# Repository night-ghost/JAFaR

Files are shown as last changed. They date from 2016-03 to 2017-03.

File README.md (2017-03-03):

The original pkendall64 version not works or even not compiles for me so this is easy-build version with almost the same functions

## pkendall64's original README follows

# JAFaR (Just Another Fatshark Receiver Module)

DIY OpenSource 40ch receiver OSD integrated

## This is a major refactor of MikyM0use's original code

**Changes**
* Added a favorites section which remembers the last 8 channels used ordered with the last used at the top of the list. It re-orders the list when you select a new channel.
* The scanner is continuously running in the main menu or scanner menu. This means that the RSSI values are pretty much always up to date.
* There's a timer progress bar on the right rather than a counter.
* Double-click (i.e. another press within 1 second) takes you back to the main menu.
* When in a band selection menu, favorites or autoscan a single click of the buttons selects the next or previous channel respectively.
* When a channel is selected, display the current RSSI for each receiver under the channel designator (only on the OLED display).
* Moved all strings in OLED and OSD to PROGMEM.

Make sure to use the updated TVout library from https://github.com/pkendall64/arduino-tvout as the original will cancel timer 2, which is the selection timer for this version of the receiver.

## MikyM0use's original README follows

The aim of the project is to build an opensource 40ch receiver for Fatshark goggles which has to be easy to develop,
upgrade and maintain. And, of course, it must be cheap!
<p align="center">
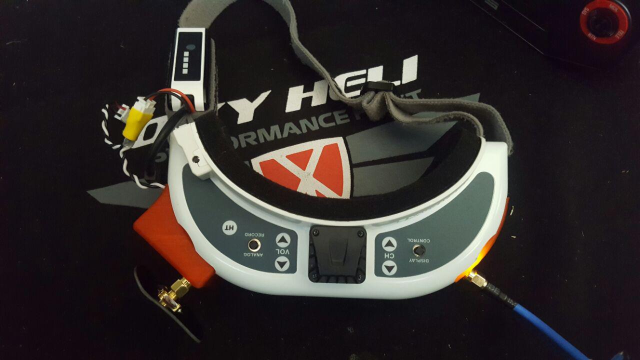
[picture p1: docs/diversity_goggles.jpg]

</p>

* 40ch (8 channels for 5 bands, including race band)
* No external switch, or hall effect sensor, or buzzer, it must use __only__ the goggles buttons (up-down)
* Auto search feature
* It should include the “scanner” feature (see my recent project here https://github.com/MikyM0use/OLED-scanner)
* Frequency selection via OSD inside the goggles
* I tested it only with Fatshark HD but the module should work with every Fatshark with the RX external module (like Dominator V1, V2, V3, HD, HD2...)

This project uses the “RX5808” receiver module, which can be hacked to be SPI-programmed by a microcontroller (more details later).
So what I needed is a micro controller with an easy and well-know software IDE… nothing better than Arduino. So I decided to use an Atmega 328p as micro controller.

To select the frequency there's a series of menus on the screen inside the goggles, the
useful TVOUT Arduino library is perfect and requires just a couple of resistors
(http://playground.arduino.cc/Main/TVout).
A digital switch (TS5A3359) allow to switch from OSD to the normal receiving video from the quadcopter.

The project is mainly divided into two PCBs:
* one main base module
* one "diversity" daughterboard (optional)

it's also possibile to use an SPI-OLED display and use the module as standalone RX.

##Table of contents
* [Main module](#main-module)
	* [DIY Instructions](#diy-instructions)
	* [MAIN MODULE Troubleshooting](#main-module-troubleshooting)
* [Diversity module](#diversity-module)
* [OLED module](#oled-module)
* [STANDALONE mode](#standalone-mode)
* [Reference thread](#reference-thread)
* [FAQ:](#faq)
* [Donations:](#donations)

##Main module

This is the main RX module, usable alone as a 40ch receiver module, but if you connect an
"external" module, the onboard microcontroller can decide which RX module has better
reception (so-called "diversity") based on the received signal strength. Indeed, this
RX5808 modules has an analog output called RSSI proportional on the "quality" of the
received video signal. The receiving video channel (frequency) is set by the user using an OSD menu.

<p align="center">
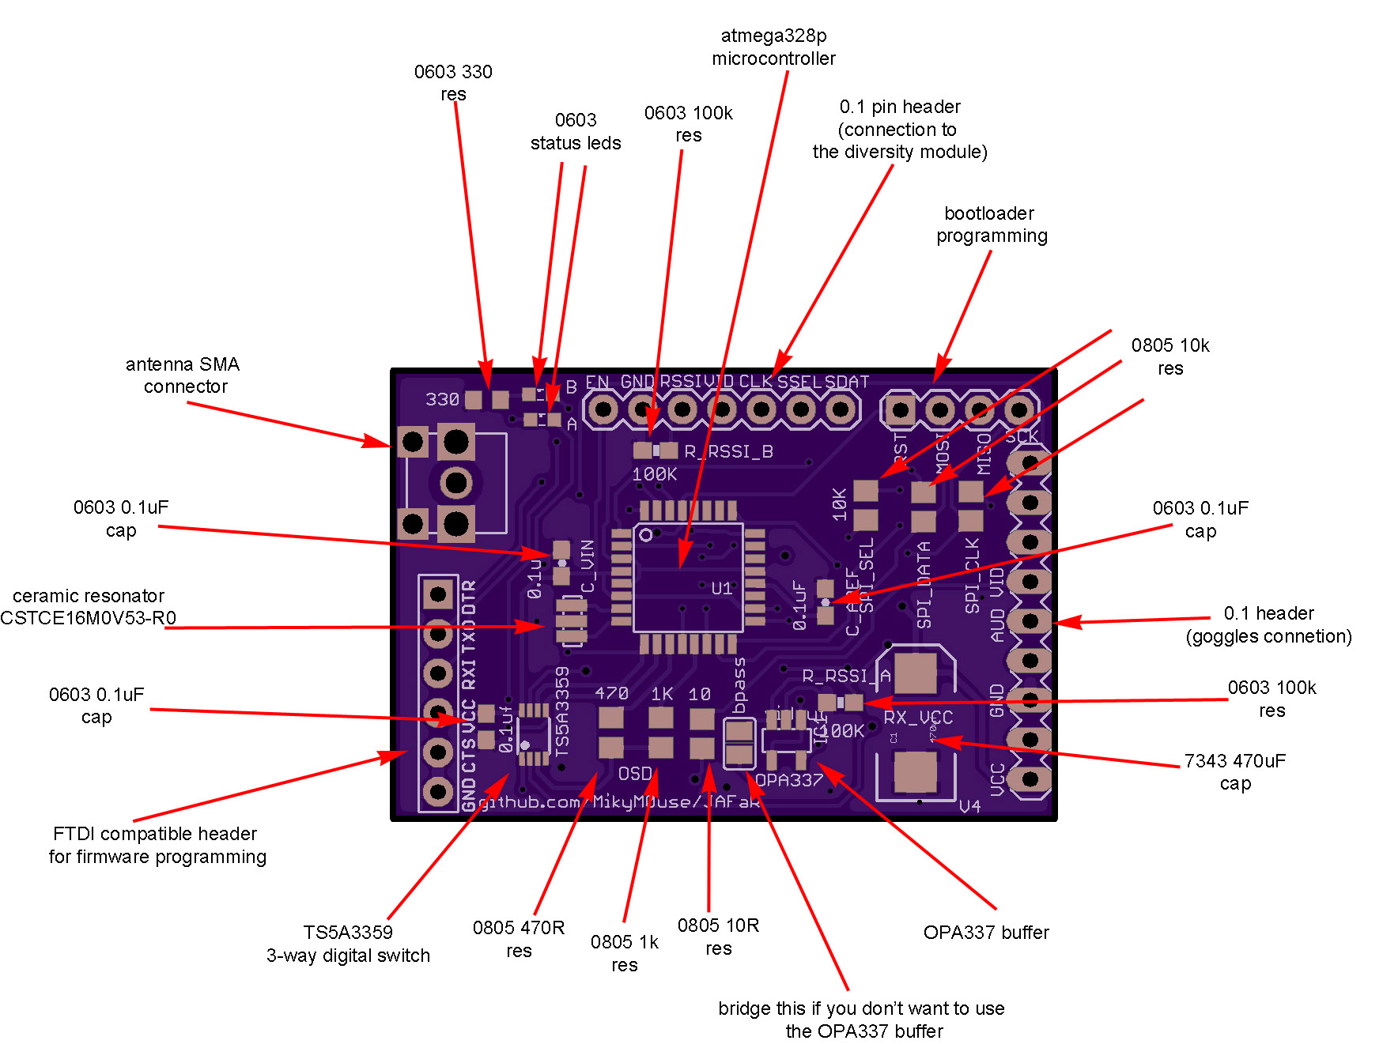
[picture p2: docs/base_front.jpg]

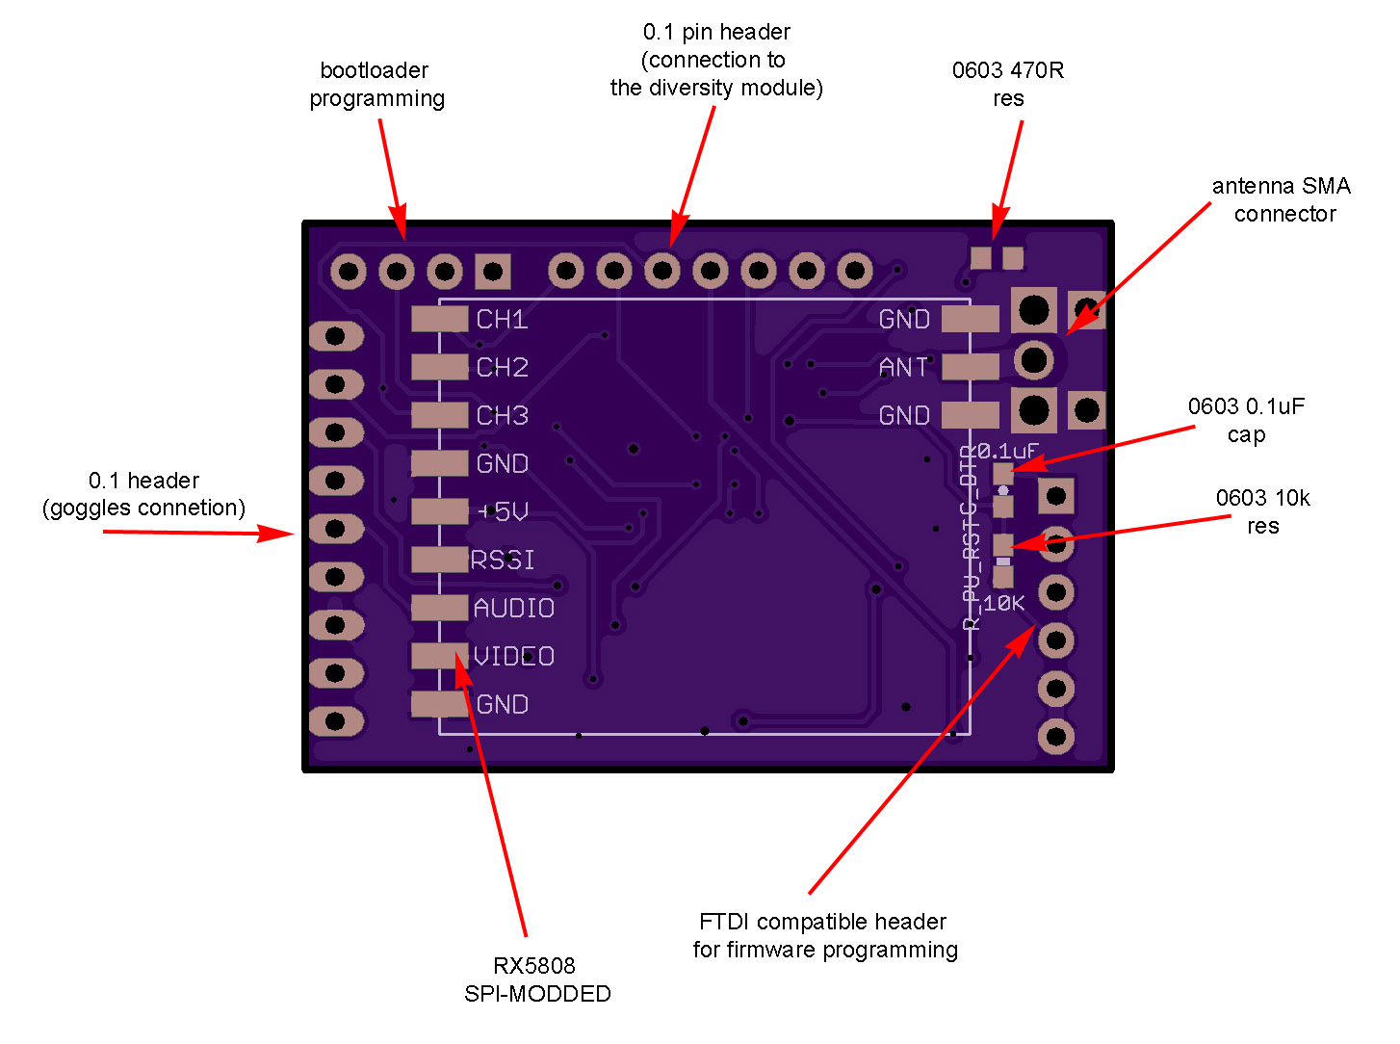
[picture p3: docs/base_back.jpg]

</p>

__MAIN MODULE (V4.0) BOM__

https://docs.google.com/spreadsheets/d/1CrZzOQHyK_d1VfHCQKwdNuoyMji0IYryI1VuffojdGA/edit?usp=sharing

__LEGACY MAIN MODULE (V3.2)__

This module is actually the same as the v4.0, but it doesn't have the buffer on the RSSI output,
and the PCB allows the use of a capacitor OR a resistor on the video out. DON'T use both! after some
tests I realized that a 10ohm resistor (and no cap) is enough.

<p align="center">
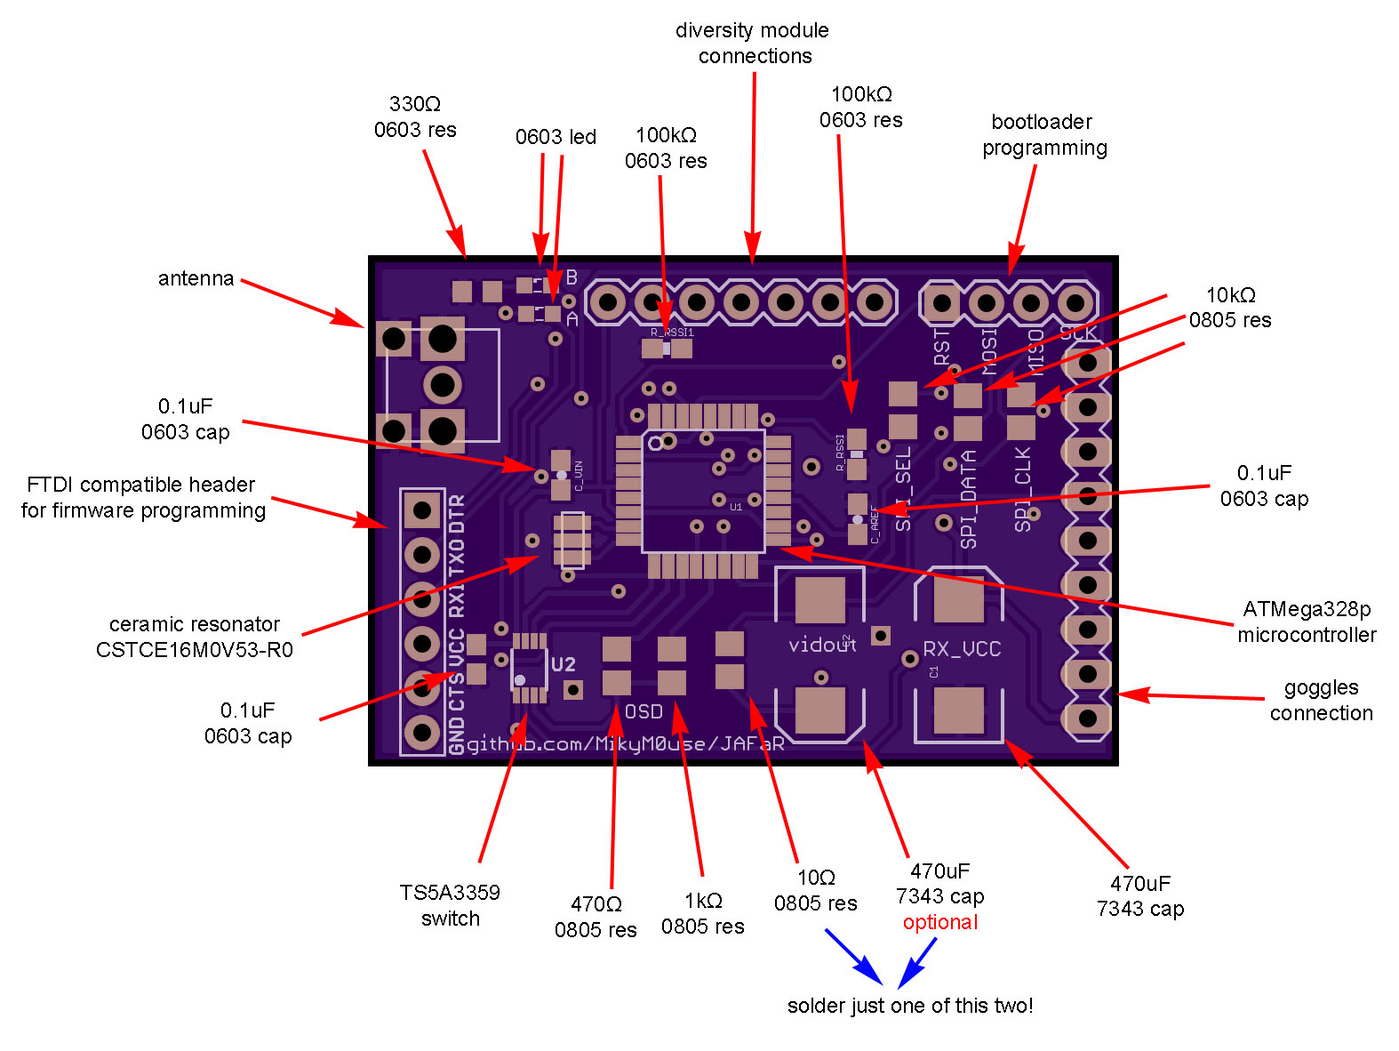
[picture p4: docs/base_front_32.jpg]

</p>

(the back side is the same of the v4.0).

__LEGACY MAIN MODULE (V3.2) BOM__

https://docs.google.com/spreadsheets/d/1-763imBV3QsQ71GKDZH-BirTz1k32szNuJZUKQrE00g/edit?usp=sharing

###DIY Instructions

1. Remove the shield of the RX5808 module and desolder the resistor marked by the arrow. This
is the SPI-mod required to control the module with an external microcontroller.

<p align="center">
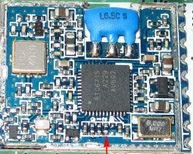
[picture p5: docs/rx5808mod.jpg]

</p>

2. Follow the instructions on the page https://www.arduino.cc/en/Tutorial/ArduinoISP to burn the bootloader (select __"Arduino Pro Mini 5v 16MHz"__ as target board)
using the pins in the upper right corner of the board

3. Use the FTDI connections in the left side of the board to upload the code present in the
Github page of the project. Please remember to copy all the subfolders of "libs" dir in the
libraries folder of Arduino (e.g. /Arduino/libraries).
Here you can find more infos and alternative methods to import the libraries:
https://www.arduino.cc/en/Guide/Libraries

4. When you power on the module, BOTH the leds (upper left corner of the pcb) must be on, and you must see a relatively stable splash screen for about 5 seconds

5. The very first time you power on the module, it need to calibrate itself. So please turn on the module with a working Vtx a couple of meter away (the video frequency doesn't matter). This process can take a while (about 30-50 seconds).

6. You can now use the "selection" buttons on the goggles to scroll up/down the menu to select the band

7. After the timout of the countdown (upper left corner of the screen) you entered the frequency selection (of the selected band)

8. Scroll up/down to select the frequency and wait the timeout

9. At this moment only one led on the module has to be ON, it means that the RX video output is routed to the video_input of the goggles. If you have a Vtx near, you should see the video coming from it.

10. If you press the "selection" buttons of the goggles now, you change the frequency by the 8 frequencies of the previously selected band.

###MAIN MODULE Troubleshooting

After the initial calibration, the module must turn on in couple of seconds and you must see the splash screen for some seconds before the "band selection" screen.
In the "band selection" screen you can see the 5 bands with the percentage of the maximum RSSI detected on that band. At least one of the band must be at 98-100%.
If you "enter" one band, every channel must shows a different percentage of RSSI, otherwise the SPI-mod of the module could be failed.

__Unable to flash/Aduino issues:__

(thanks to pHysiX for the help in this section!)
Got the error "no reply" when trying to load the firmware:
the ATmega microcontroller is not soldered properly / there is a short on some pins.
try a quick solder, clean and reflow.

Got the error "incorrect signature" when trying to load the firmware:
This means Arduino is able to pick up the ATMega, but it was not communicating as expected.
This is related to poor soldering of the crystal. It's possible to do the crystal using
an iron, but I strongly recommend using flow method/hot air to do this, to make sure you
don't short the three legs accidentally onto the metal case.

__Display issues:__

They are mostly related to poor soldering for the OSD components on the board. Go back and
reflow especially the Switch, and then just make sure to clean up and touch up all the caps
and resistors near and around the switch.

If you have an external monitor, you can bypass the digital switch by power on the module with external 5v and connecting the "video in" of the monitor on the test point marked in yellow the picture:

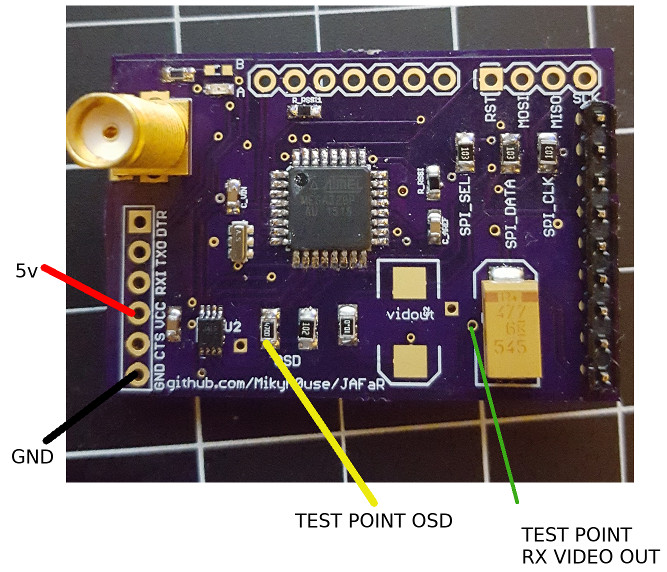
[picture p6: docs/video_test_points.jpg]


and you should see the splash screen and the menu.

If you connect the "video in" of the monitor to the test point marked in green, you should see the initial scanning (used to determine the % of the RSSI on each channel), this means a sequence of different "fogs" and (at least) one "good" image (for a fraction of second), if you have a Vtx + cam transmitting.

__Frequency issues:__

If the module is having trouble Setting Frequency, or you are not getting video when you are
on the right channel and frequency, make sure the SPI mod has been done, and that the RX5808
is soldered on well. Pretty hard to mess this part up.

##Diversity module

The diversity module is an optional second receiver, connected to the "main" base module, it has:
* integrated linear 5v regulator with ENABLE feature connected to the VCC of the main module.
In fact power a second module from the internal goggles voltage regulator IS VERY DANGEROUS!
* an optional operational buffer for RSSI signal (I noticed that lately modules seems to be more delicate)

<p align="center">
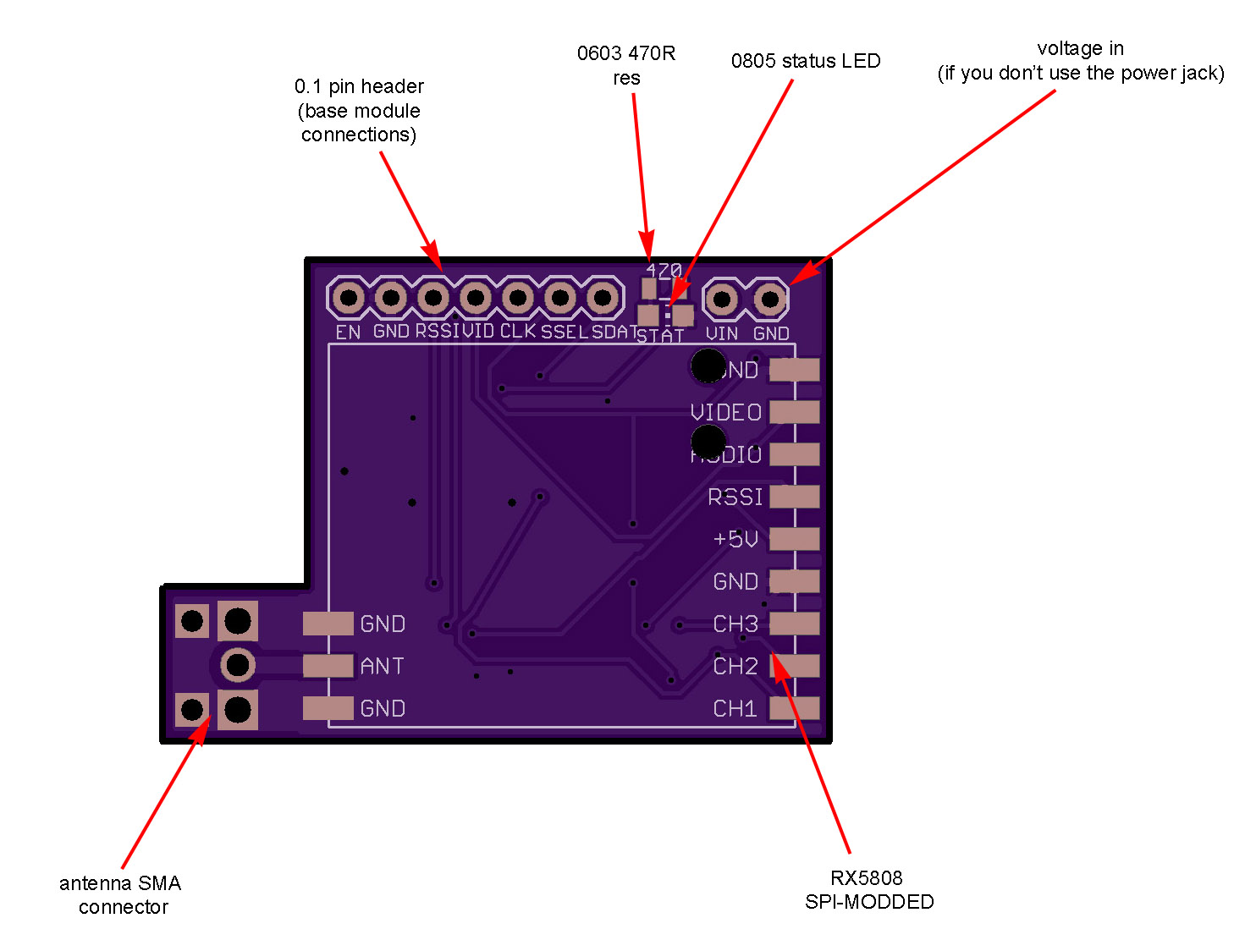
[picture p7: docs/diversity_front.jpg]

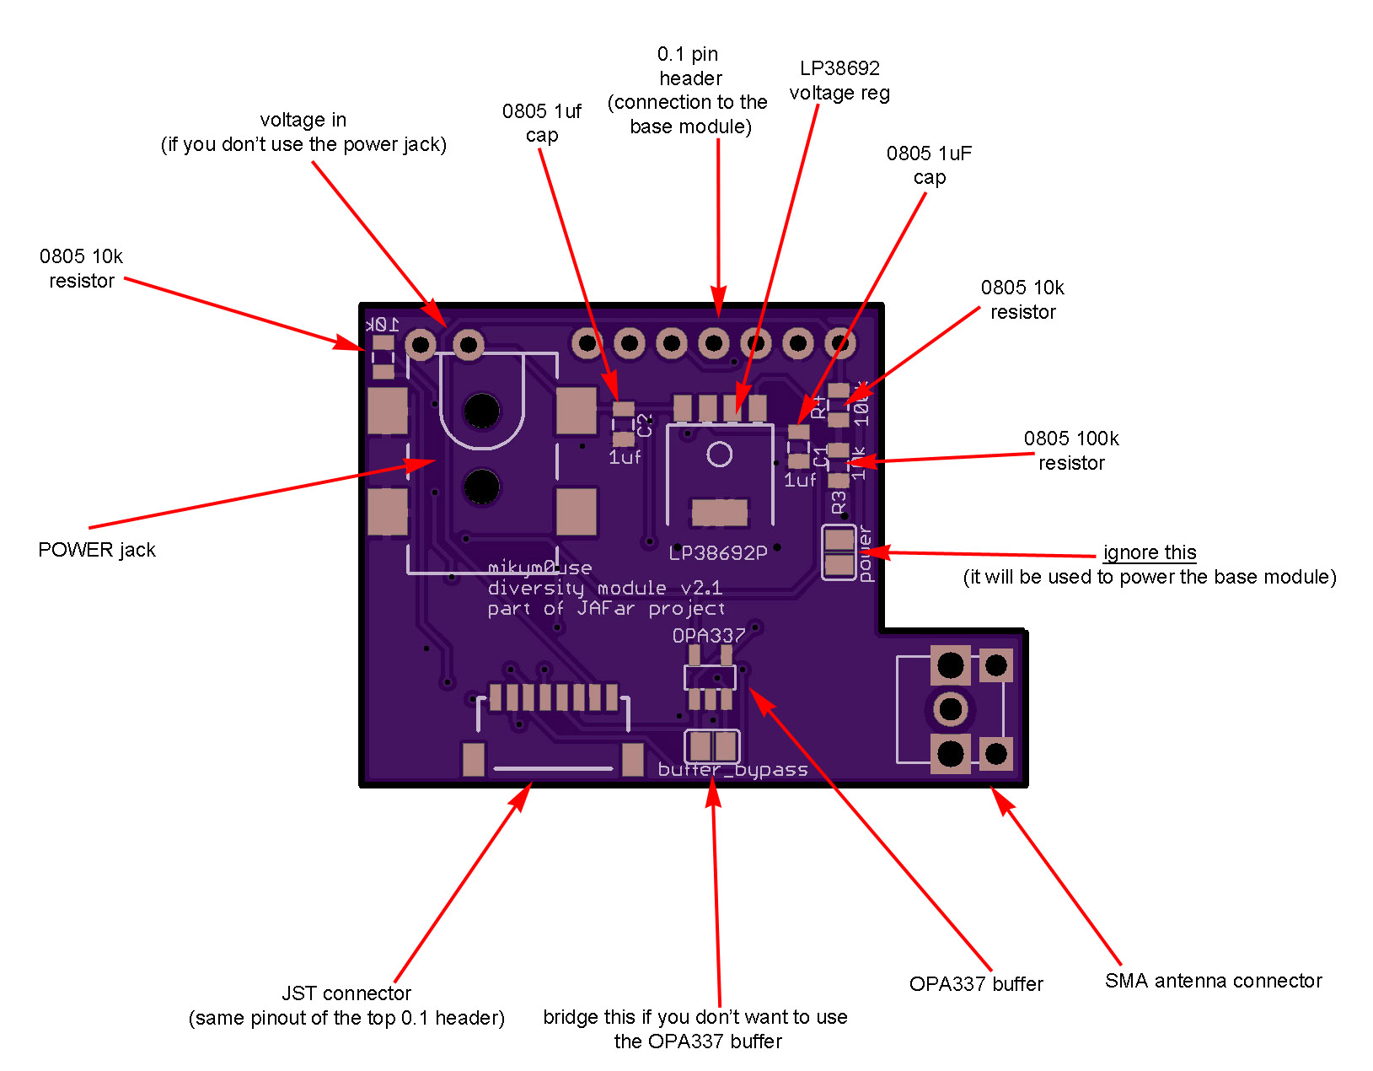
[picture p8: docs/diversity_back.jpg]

</p>

please notice that because of the linear regulator it's not possibile to use a 3s battery to power the diversity module.

__DIVERSITY MODULE (V2.1) BOM__

https://docs.google.com/spreadsheets/d/1OpagubuxicmGTKqOHWwWdxZxY6wCs_DZqTYRxVoD4Tc/edit?usp=sharing

##OLED module
It's possible to use an external SPI OLED module in case of any problems with the internal OSD
or to use the module with an external monitor / different goggles.

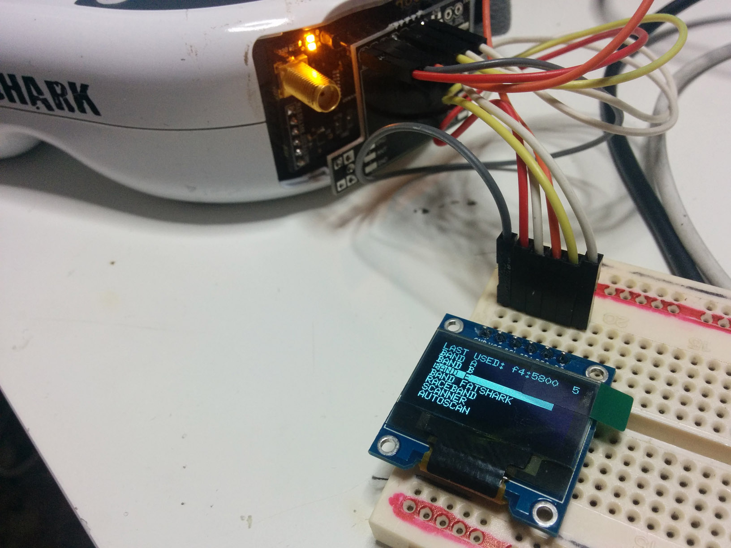
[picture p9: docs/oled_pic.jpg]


It's important that the module has only SDA/SCL/RES/DC pins.

To use the OLED module instead of the internal OSD, uncomment  the line:

```
#define USE_OLED
```

in the file const.h

please remember to comment #define USE_DIVERSITY!

__Connections__

| ATMEGA328p pin |  PCB silkscreen name | OLED silkscreen name  |
| :---:	|:---:| :---:|
| VCC 				| 		EN 						| 		VCC 			|
| GND 				| GND 							| 					GND |
| 8 				| SSEL 							| 				SCL 	|
| A1 				| RSSI 					| 		SDA 		|
| A4 					|  NOT CONNECTED 			| 	NOT CONNECTED 	|
| 11 					| SDA 						| DC 				|
| 13				 	| CLK 						| RESET 				|

...or graphically:

<p align="center">
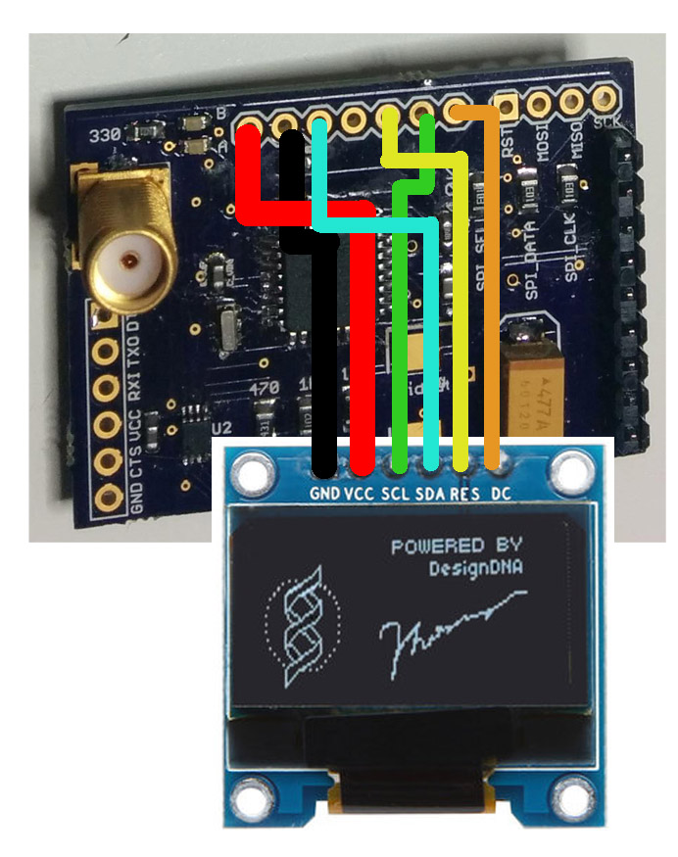
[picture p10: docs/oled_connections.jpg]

</p>

there's also a "PCB" inside the PCBs folder, but it's just a simple adaptor.

##Standalone mode

It's possible to use the project also as a standalone receiver to be used in combination
with any external monitor or other kind of goggles.

In this case you must uncomment the line

```
#define STANDALONE
```

in the file const.h. You can use the standalone mode either with OSD or with the external SPI OLED module.

to change band/channel, the connections are the following (every normally-open momentary switch will do the job):

<p align="center">
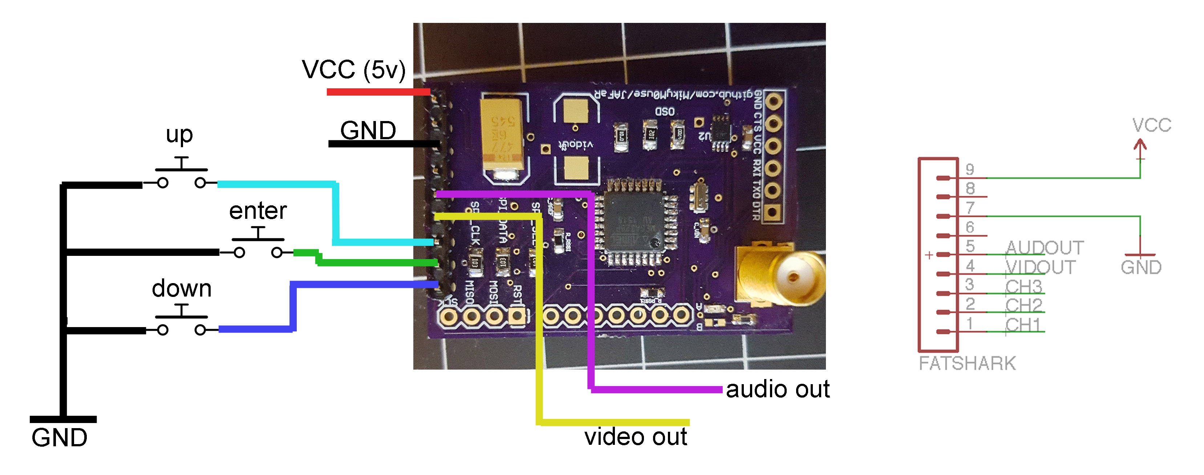
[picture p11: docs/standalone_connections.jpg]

</p>

##Reference thread

http://www.rcgroups.com/forums/showthread.php?t=2619124 while I'm still writing the readme :)

##FAQ

why the OSD is on the blank screen?
it’s simpler because one cannot have to recognize the vsync and the hsync pulses.

why the switch is so small and hard to solder?!?
I need a small 3-way switch, if you have a "simpler" one, just tell me :)

please note that you try and use this project AT YOUR OWN RISK!

##Donations

Hardware or paypal donations to carry on the project are always accepted.



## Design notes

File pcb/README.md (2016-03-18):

PLEASE READ THIS BEFORE GO FURTHER!

THIS PCB IS VERY EXPERIMENTAL! TRY IT AT YOUR OWN RISK!

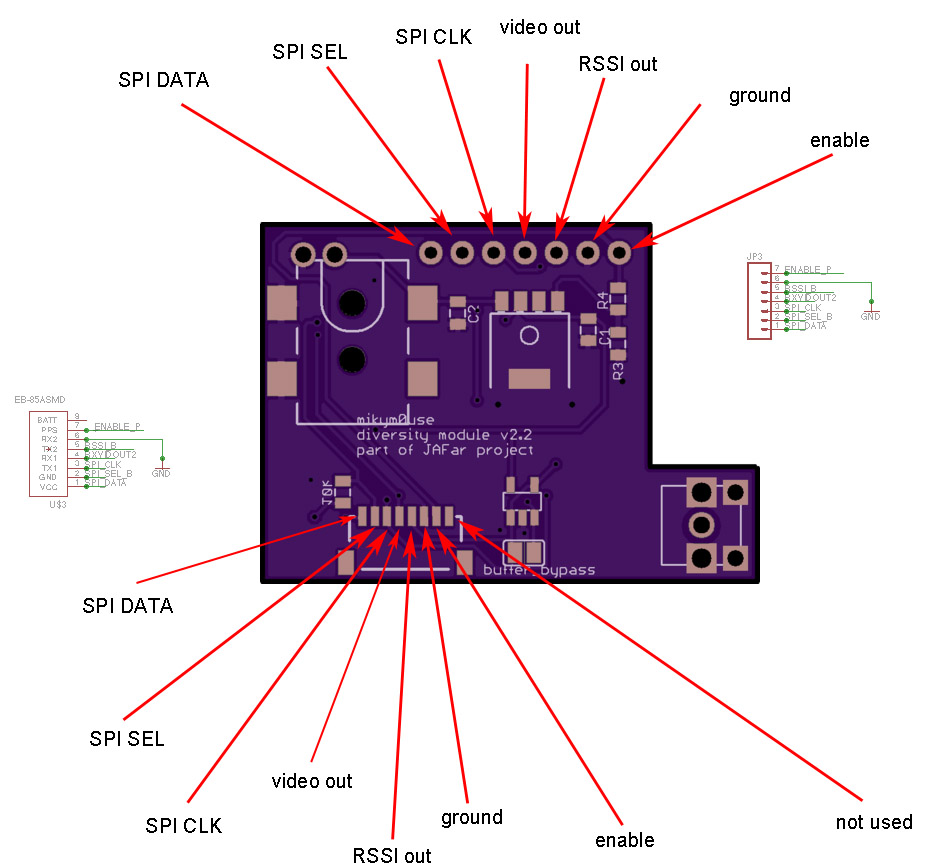
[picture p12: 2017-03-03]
docs/diversity_pinout.jpg

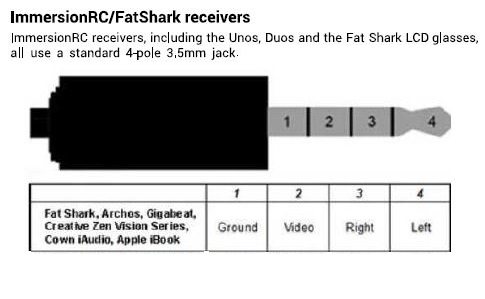
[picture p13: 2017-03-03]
pcb/standalone_module/goggle-pinout.jpg

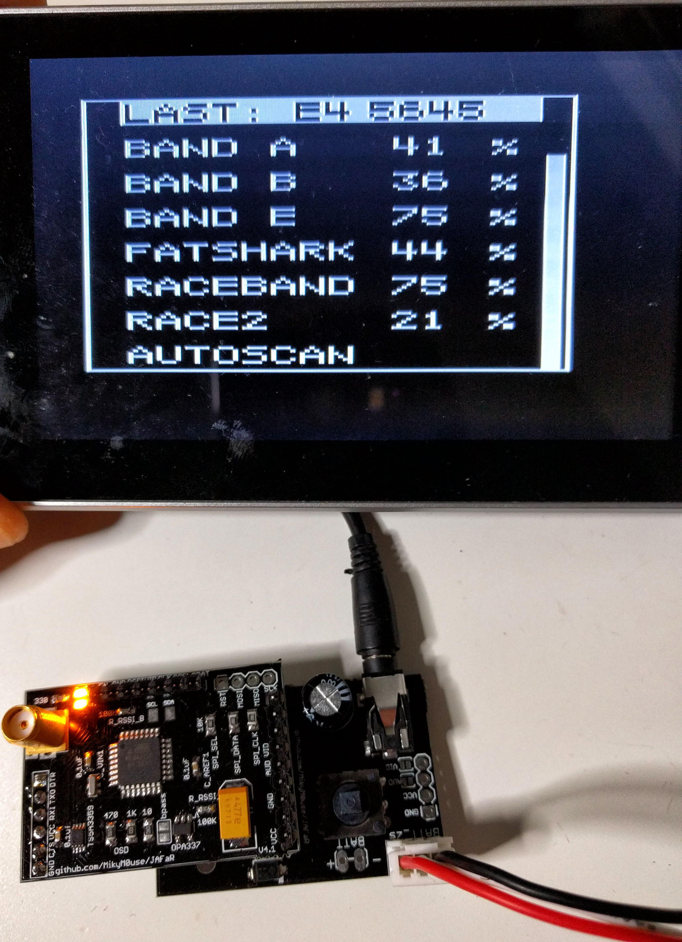
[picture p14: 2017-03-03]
docs/standalone_module_mount.jpg

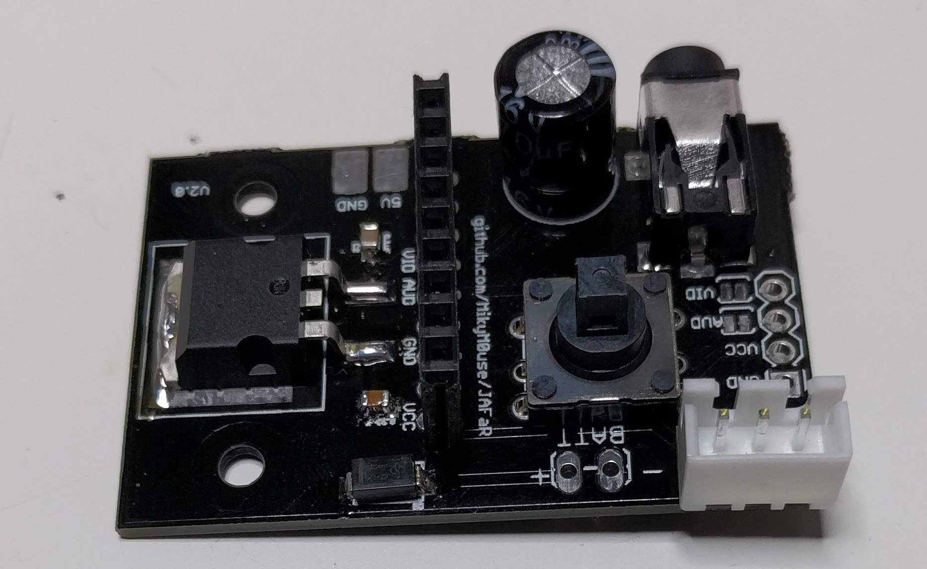
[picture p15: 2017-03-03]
docs/standalone_module.jpg

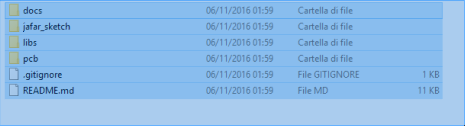
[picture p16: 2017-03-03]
docs/directory_struct.png

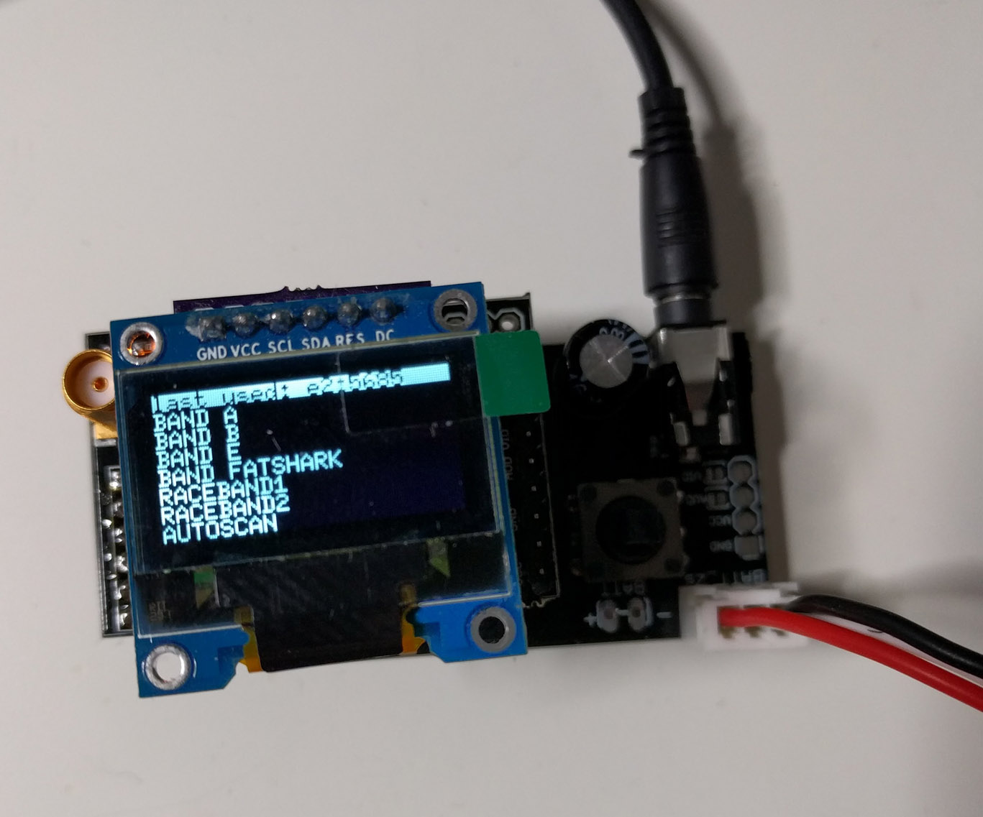
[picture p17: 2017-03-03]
docs/standalone_module_oled.jpg

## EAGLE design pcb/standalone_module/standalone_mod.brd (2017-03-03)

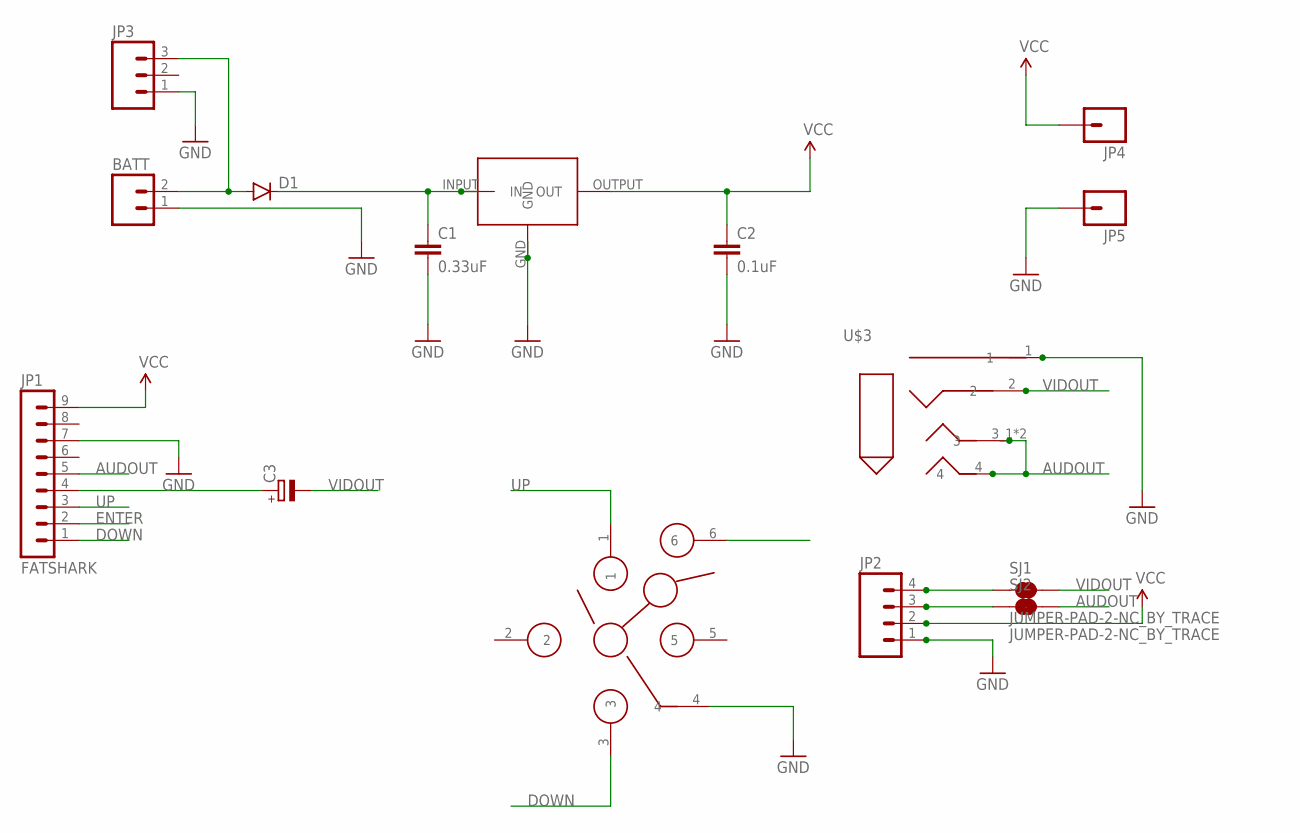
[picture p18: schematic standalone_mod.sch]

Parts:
BATT: M02LOCK_LONGPADS; 1X02_LOCK_LONGPADS
C1: 0.33uF; 0805
C2: 0.1uF; 0805
C3: CPOL-EUE3.5-8; E3,5-8
D1: DIODESMA; SMA-DIODE
JP1: FATSHARK; MA09-1
JP2: M04PTH; 1X04
JP3: M03LONGPADS; 1X03_LONGPADS
JP4, JP5: M01SMD; LUXEON-PAD
SJ1, SJ2: JUMPER-PAD-2-NC_BY_TRACE; PAD-JUMPER-2-NC_BY_TRACE_YES_SILK
U$1: 7805; DDPAK
U$2: SKQUCAA010
U$3: MC001293JACK; MC001293

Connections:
5V: C2.1, JP1.9, JP2.2, JP4.P$1, U$1.OUTPUT (OUT)
AUDOUT: JP1.5, SJ2.2, U$3.3_1 (3), U$3.3_2 (3), U$3.4
DOWN: JP1.1, U$2.3
ENTER: JP1.2, U$2.6
GND: BATT.1, C1.2, C2.2, JP1.7, JP2.1, JP3.1, JP5.P$1, U$1.GND, U$2.4, U$3.1
unnamed: C1.1, D1.C, U$1.INPUT (IN)
unnamed: C3.+, JP1.4
unnamed: BATT.2, D1.A, JP3.3
unnamed: JP2.4, SJ1.1
unnamed: JP2.3, SJ2.1
UP: JP1.3, U$2.1
VIDOUT: C3.-, SJ1.2, U$3.2

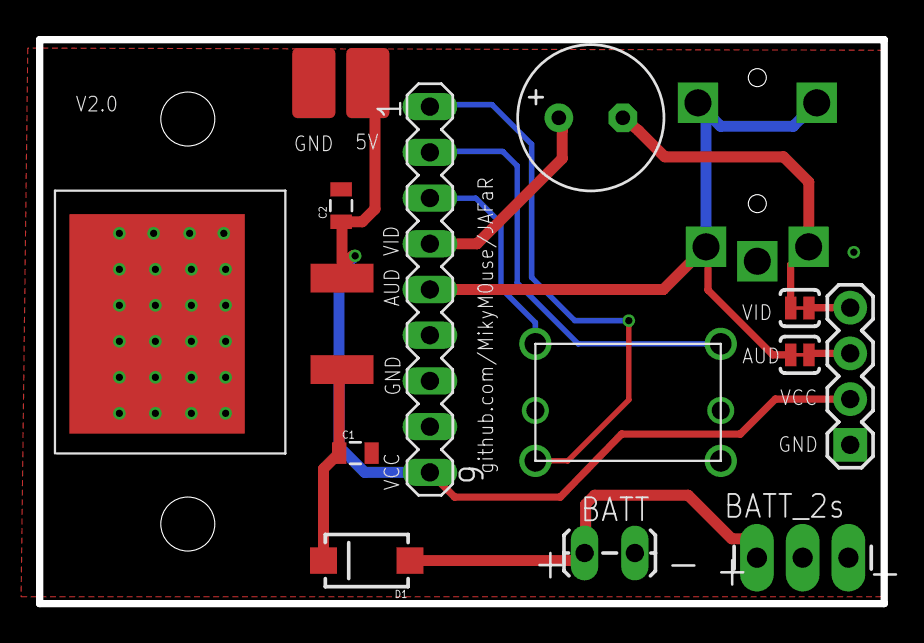
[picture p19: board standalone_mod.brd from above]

Board: 2 copper layers, 46.9 x 31.3 mm, 15 parts (0 on the bottom side), 12 nets.

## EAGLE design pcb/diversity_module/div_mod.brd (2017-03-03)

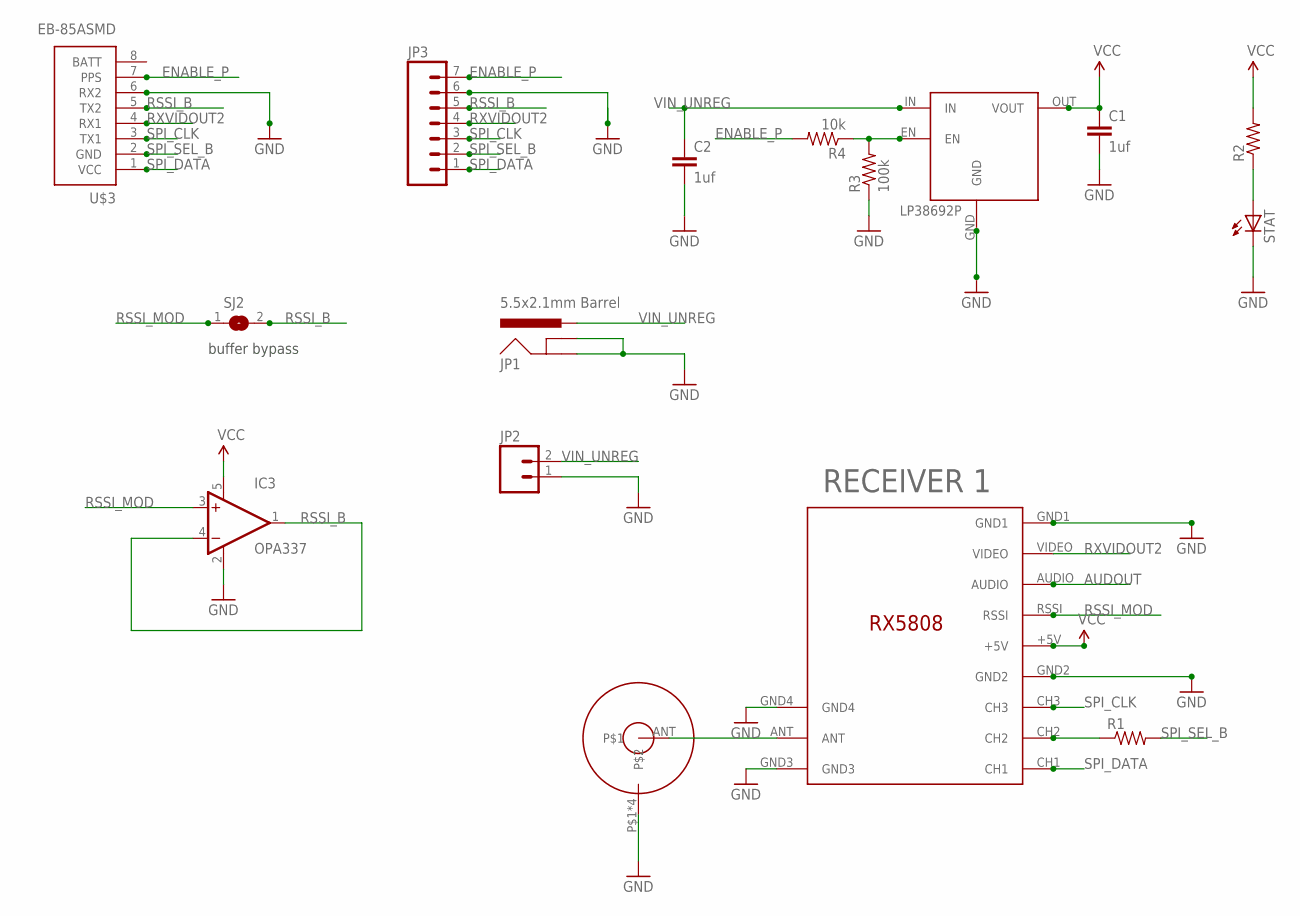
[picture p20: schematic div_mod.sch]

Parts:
C1, C2: 1uf; 0805
IC3: OPA336N; SOT23-5
JP1: 5.5x2.1mm Barrel; POWER_JACK_SMD
JP2: M02PTH; 1X02
JP3: M07; 1X07
R1, R2: RESISTOR0805-RES; 0805
R3: 100k; 0805
R4: 10k; 0805
RECEIVER_A: RX5808_A; RX5808
SJ2: SJ
STAT: LEDCHIP-LED0805; CHIP-LED0805
U$1: SMA_ANTENNA; SMA_CONNECTOR
U$3: EB-85ASMD; EB-85A
V1: LP38692P; TO252-51

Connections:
5V: C1.1, IC3.5 (V+), R2.2, RECEIVER_A.+5V, V1.OUT (VOUT)
AUDOUT: RECEIVER_A.AUDIO
BATT: U$3.8 (BATT)
ENABLE: R3.2, R4.1, V1.EN
ENABLE_P: JP3.7, R4.2, U$3.7 (PPS)
GND: C1.2, C2.2, IC3.2 (V-), JP1.GND (GNDBREAK), JP1.P$4 (GND), JP2.1, JP3.6, R3.1, RECEIVER_A.GND1, RECEIVER_A.GND2, RECEIVER_A.GND3, RECEIVER_A.GND4, STAT.C, U$1.P$1, U$1.P$2, U$1.P$3, U$1.P$4, U$3.6 (RX2), V1.GND
unnamed: R1.1, RECEIVER_A.CH2
unnamed: R2.1, STAT.A
unnamed: RECEIVER_A.ANT, U$1.ANT
RSSI_B: IC3.1 (OUT), IC3.4 (-IN), JP3.5, SJ2.2, U$3.5 (TX2)
RSSI_MOD: IC3.3 (+IN), RECEIVER_A.RSSI, SJ2.1
RXVIDOUT2: JP3.4, RECEIVER_A.VIDEO, U$3.4 (RX1)
SPI_CLK: JP3.3, RECEIVER_A.CH3, U$3.3 (TX1)
SPI_DATA: JP3.1, RECEIVER_A.CH1, U$3.1 (VCC)
SPI_SEL_B: JP3.2, R1.2, U$3.2 (GND)
VIN_UNREG: C2.1, JP1.VIN0 (PWR), JP2.2, V1.IN

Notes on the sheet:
RECEIVER 1
buffer bypass
OPA337

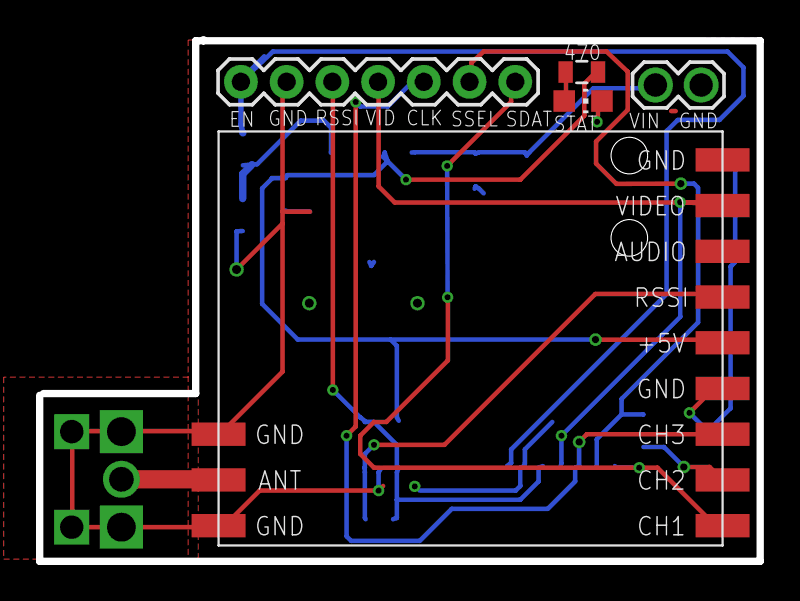
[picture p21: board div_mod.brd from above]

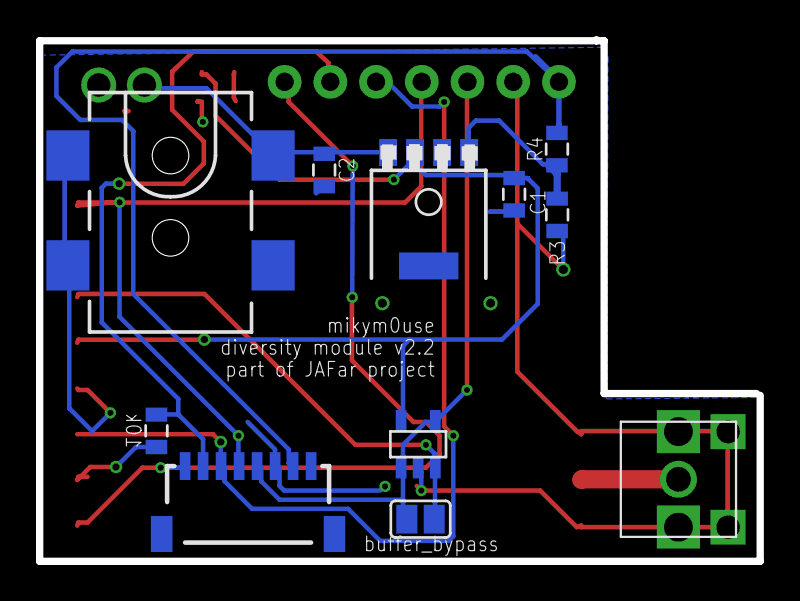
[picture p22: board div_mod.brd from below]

Board: 2 copper layers, 40.0 x 28.9 mm, 16 parts (11 on the bottom side), 14 nets.

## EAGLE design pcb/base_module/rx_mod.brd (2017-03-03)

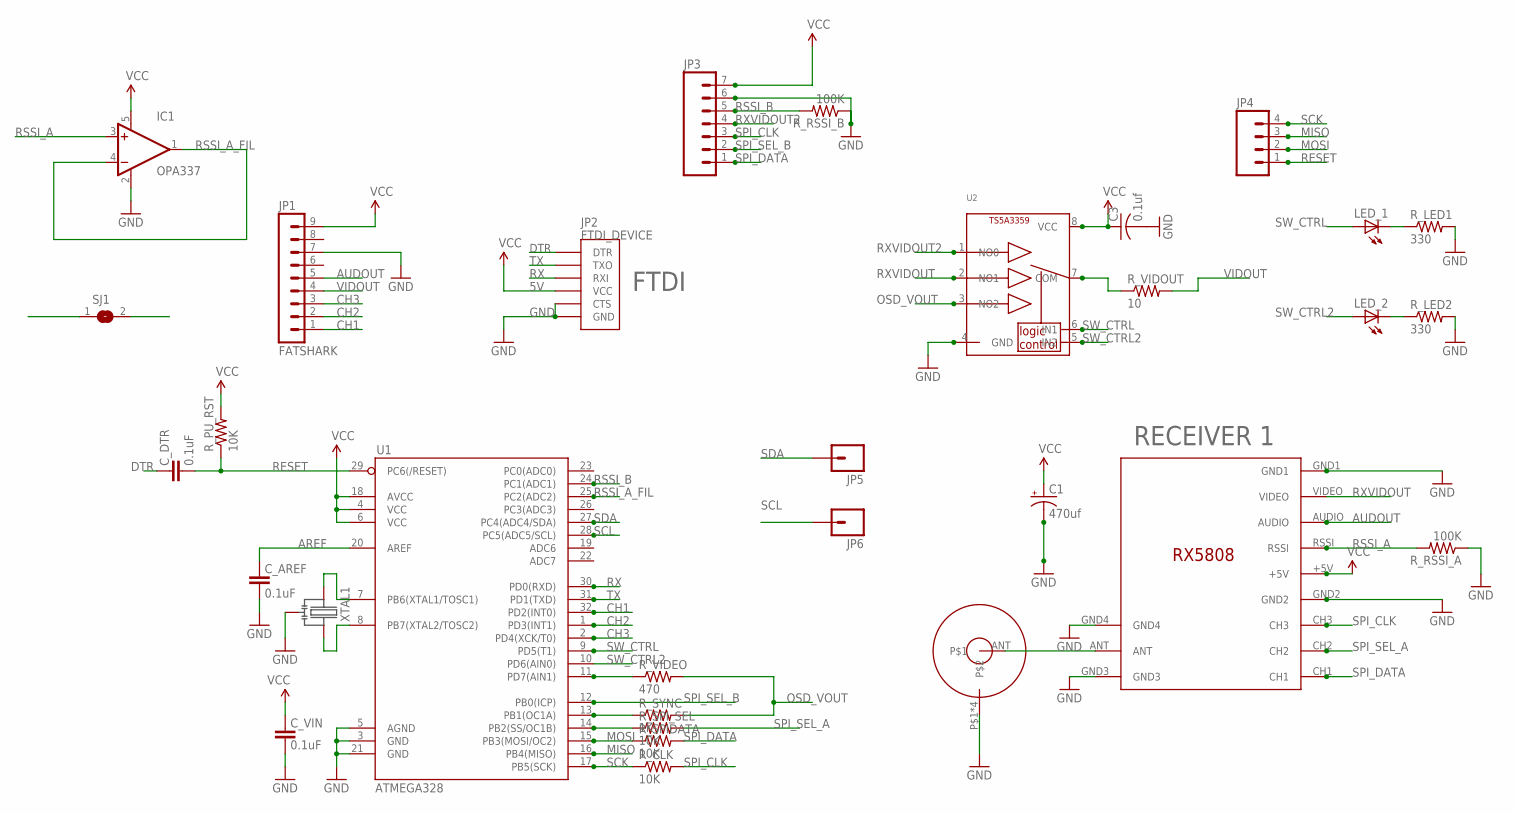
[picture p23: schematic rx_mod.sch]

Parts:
C1: 470uf; EIA7343
C3: 0.1uf; C0603
C_AREF: 0.1uF; 0603-CAP
C_DTR: 0.1uF; 0603-CAP
C_VIN: 0.1uF; 0603-CAP
IC1: OPA336N; SOT23-5
JP1: FATSHARK; MA09-1
JP2: FTDI_DEVICE; FTDI_DEVICE_SIDE
JP3: M07; 1X07
JP4: M04PTH; 1X04
JP5, JP6: M01SMD-4.5X1.5; PAD-1.5X4.5
LED_1, LED_2: LEDSML0603; SML0603
RECEIVER_A: RX5808_A; RX5808
R_CLK: 10K; R0805
R_LED1, R_LED2: 330; R0603
R_PU_RST: 10K; 0603-RES
R_RSSI_A: 100K; 0603-RES
R_RSSI_B: 100K; 0603-RES
R_SPIDATA: 10K; R0805
R_SPI_SEL: 10K; R0805
R_SYNC: 1K; R0805
R_VIDEO: 470; R0805
R_VIDOUT: 10; R0805
SJ1: SJ
U1: ATMEGA328; TQFP32-08
U2: TS5A3359; VFSOP-8
U$1: SMA_ANTENNA; SMA_CONNECTOR
XTAL1: CSTCE16M0V53-R0

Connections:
5V: C1.A (+), C3.1, C_VIN.2, IC1.5 (V+), JP1.9, JP2.P$4 (VCC), JP3.7, RECEIVER_A.+5V, R_PU_RST.2, U1.4 (VCC), U1.6 (VCC), U1.18 (AVCC), U2.8 (VCC)
AREF: C_AREF.2, U1.20 (AREF)
AUDOUT: JP1.5, RECEIVER_A.AUDIO
CH1: JP1.1, U1.32 (PD2(INT0))
CH2: JP1.2, U1.1 (PD3(INT1))
CH3: JP1.3, U1.2 (PD4(XCK/T0))
DTR: C_DTR.2, JP2.P$1 (DTR)
GND: C1.C (-), C3.2, C_AREF.1, C_VIN.1, IC1.2 (V-), JP1.7, JP2.P$5 (CTS), JP2.P$6 (GND), JP3.6, RECEIVER_A.GND1, RECEIVER_A.GND2, RECEIVER_A.GND3, RECEIVER_A.GND4, R_LED1.2, R_LED2.2, R_RSSI_A.1, R_RSSI_B.1, U1.3 (GND), U1.5 (AGND), U1.21 (GND), U2.4 (GND), U$1.P$1, U$1.P$2, U$1.P$3, U$1.P$4, XTAL1.2
MISO: JP4.3, U1.16 (PB4(MISO))
MOSI: JP4.2, R_SPIDATA.1, U1.15 (PB3(MOSI/OC2))
unnamed: U1.8 (PB7(XTAL2/TOSC2)), XTAL1.3
unnamed: U1.7 (PB6(XTAL1/TOSC1)), XTAL1.1
unnamed: LED_1.C, R_LED1.1
unnamed: R_SPI_SEL.1, U1.14 (PB2(SS/OC1B))
unnamed: RECEIVER_A.ANT, U$1.ANT
unnamed: R_VIDOUT.1, U2.7 (COM)
unnamed: R_SYNC.1, U1.13 (PB1(OC1A))
unnamed: R_VIDEO.1, U1.11 (PD7(AIN1))
unnamed: LED_2.C, R_LED2.1
OSD_VOUT: R_SYNC.2, R_VIDEO.2, U2.3 (NO2)
RESET: C_DTR.1, JP4.1, R_PU_RST.1, U1.29 (PC6(/RESET))
RSSI_A: IC1.3 (+IN), RECEIVER_A.RSSI, R_RSSI_A.2, SJ1.1
RSSI_A_FIL: IC1.1 (OUT), IC1.4 (-IN), SJ1.2, U1.25 (PC2(ADC2))
RSSI_B: JP3.5, R_RSSI_B.2, U1.24 (PC1(ADC1))
RX: JP2.P$3 (RXI), U1.30 (PD0(RXD))
RXVIDOUT: RECEIVER_A.VIDEO, U2.2 (NO1)
RXVIDOUT2: JP3.4, U2.1 (NO0)
SCK: JP4.4, R_CLK.1, U1.17 (PB5(SCK))
SCL: JP6.P$1, U1.28 (PC5(ADC5/SCL))
SDA: JP5.P$1, U1.27 (PC4(ADC4/SDA))
SPI_CLK: JP3.3, RECEIVER_A.CH3, R_CLK.2
SPI_DATA: JP3.1, RECEIVER_A.CH1, R_SPIDATA.2
SPI_SEL_A: RECEIVER_A.CH2, R_SPI_SEL.2
SPI_SEL_B: JP3.2, U1.12 (PB0(ICP))
SW_CTRL: LED_1.A, U1.9 (PD5(T1)), U2.6 (IN1)
SW_CTRL2: LED_2.A, U1.10 (PD6(AIN0)), U2.5 (IN2)
TX: JP2.P$2 (TXO), U1.31 (PD1(TXD))
VIDOUT: JP1.4, R_VIDOUT.2

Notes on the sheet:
RECEIVER 1
FTDI
OPA337

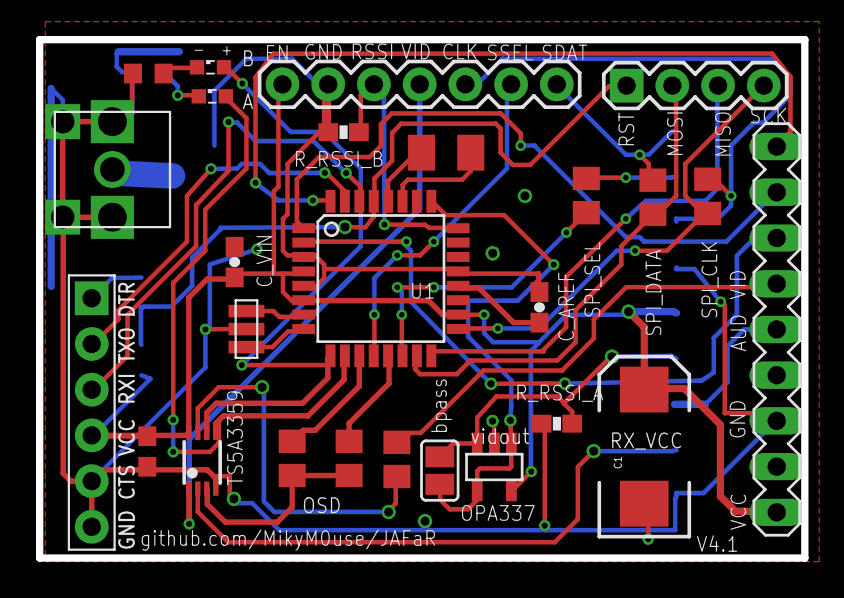
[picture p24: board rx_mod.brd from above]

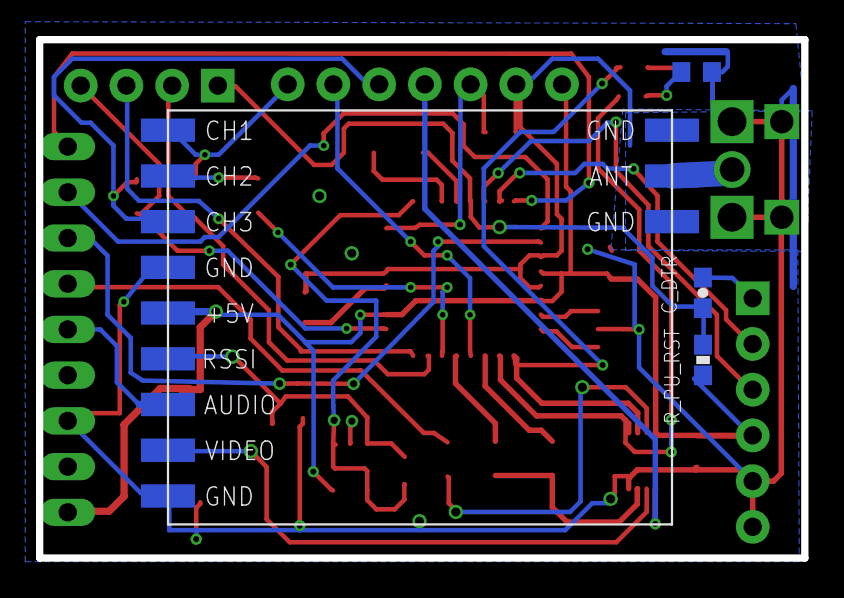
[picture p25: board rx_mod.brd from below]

Board: 2 copper layers, 42.5 x 28.8 mm, 31 parts (4 on the bottom side), 38 nets.

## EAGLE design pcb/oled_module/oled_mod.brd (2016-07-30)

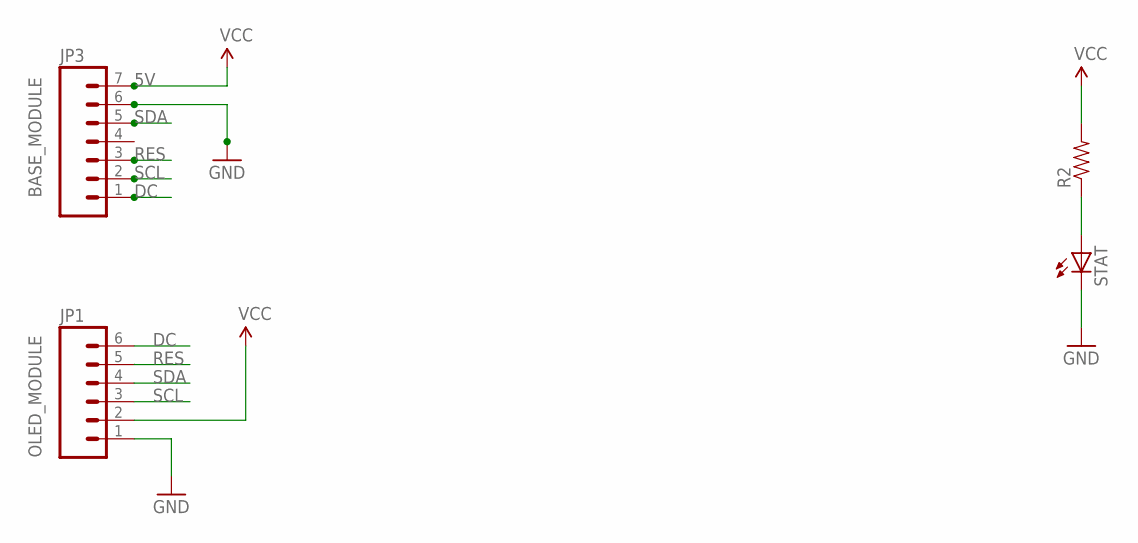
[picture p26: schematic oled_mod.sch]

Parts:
JP1: M06SILK_FEMALE_PTH; 1X06
JP3: M07; 1X07
R2: RESISTOR0805-RES; 0805
STAT: LEDCHIP-LED0805; CHIP-LED0805

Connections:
5V: JP1.2, JP3.7, R2.2
DC: JP1.6, JP3.1
GND: JP1.1, JP3.6, STAT.C
unnamed: R2.1, STAT.A
RES: JP1.5, JP3.3
SCL: JP1.3, JP3.2
SDA: JP1.4, JP3.5

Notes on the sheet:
BASE_MODULE
OLED_MODULE

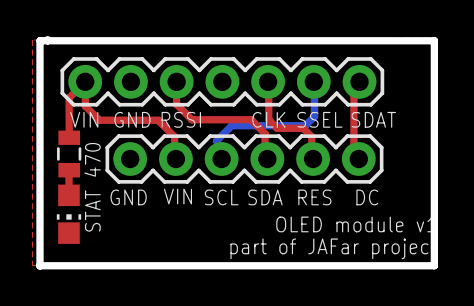
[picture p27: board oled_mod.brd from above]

Board: 2 copper layers, 21.9 x 12.5 mm, 4 parts (0 on the bottom side), 7 nets.

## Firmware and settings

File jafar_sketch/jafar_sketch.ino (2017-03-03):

/*
This file is part of Fatshark© goggle rx module project (JAFaR).

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
    Copyright © 2016 Michele Martinelli
  */

#include <Arduino.h>
#include <SPI.h>
//#include <Wire.h>
//#include <EEPROM.h>

#include <stdio.h>

#include "rx5808.h"
#include "const.h"


RX5808 rx5808(rssiA, SPI_CSA);
#ifdef USE_DIVERSITY
RX5808 rx5808B(rssiB, SPI_CSB);
#endif

volatile uint16_t counter;
volatile bool buttonPressed;
volatile bool timerExpired;

uint8_t flag_first_pos, menu_band, current_rx;
uint8_t last_used_chans[8];
uint8_t prev_last_used_chans[8];
uint8_t menu_pos;
int16_t chan_scan;

bool saved;

enum modes {
  MAINMENU,
  SCANNER,
  LASTUSED,
  BANDMENU,
  AUTOSCAN
} mode;

char j_buf[40];



#ifdef USE_OLED

#include "U8glib.h"

#ifdef USE_I2C_OLED
U8GLIB_SSD1306_128X64 u8g(U8G_I2C_OPT_DEV_0|U8G_I2C_OPT_NO_ACK|U8G_I2C_OPT_FAST);
#else
U8GLIB_SSD1306_128X64 u8g(8, A1, A4, 11 , 13); //CLK, MOSI, CS, DC, RESET
#endif

#else //USE OSD




#include <TVout.h>
//#include <TVoutfonts/fontALL.h>
#include <font4x6.h>
#include <font6x8.h>
TVout TV;

#endif //USE OSD

#include "jafar_osd.h"
#include "jafar_oled.h"


void timer_proc();

//////********* SETUP ************////////////////////
void setup() {
#ifdef DEBUG
  Serial.begin(9600);
#endif

#ifdef STANDALONE
  pinMode(CH1, INPUT_PULLUP); //UP
  pinMode(CH2, INPUT_PULLUP); //ENTER
  pinMode(CH3, INPUT_PULLUP); //DOWN
#endif
  //menu_pos = 5;

  //video out init
  pinMode(SW_CTRL1, OUTPUT);
  pinMode(SW_CTRL2, OUTPUT);
  SELECT_OSD;

  //initialize SPI
  pinMode(spiDataPin, OUTPUT);
  pinMode(spiClockPin, OUTPUT);

  display_init();


  //RX module init
  rx5808.init();
#ifdef USE_DIVERSITY
  rx5808B.init();
#endif
  //rx5808.calibration();

  display_splash_rssi();

  chan_scan = 0;

  flag_first_pos = 0;
#ifdef FORCE_FIRST_MENU_ITEM
  flag_first_pos = readSwitch();
#endif

    eeprom_read_len(last_used_chans, EEPROM_ADDR_LAST_CHAN_ID, sizeof(last_used_chans));
    

  buttonPressed = false;
  pciSetup(2);
  pciSetup(3);
  pciSetup(4);

  menu_pos = readSwitch();
  mode = MAINMENU;

  saved = false;

  display_mainmenu(menu_pos);

#if 1
  cli();
  //set timer2 interrupt at ~100Hz
  TCCR2A = 0;// set entire TCCR2A register to 0
  TCCR2B = 0;// same for TCCR2B
  TCNT2  = 0;//initialize counter value to 0
  // set compare match register for ~100Hz increments
  OCR2A = 155;// = (16*10^6) / (100*1024) - 1 (must be <256)
  // turn on CTC mode
  TCCR2A |= (1 << WGM21);
  // Set CS20 & CS22 bit for 1024 prescaler
  TCCR2B |= (1 << CS20) | (1 << CS21) | (1 << CS22);
  // enable timer compare interrupt
  TIMSK2 |= (1 << OCIE2A);

#else 
    TV.set_vsync_callback(timer_proc);
#endif

  counter = 500; // 5s
  timerExpired = false;


  sei();
}

void _delay(uint32_t t){
    TV.delay(t);
}


void pciSetup(byte pin) {
  *digitalPinToPCMSK(pin) |= bit (digitalPinToPCMSKbit(pin));  // enable pin
  PCIFR  |= bit (digitalPinToPCICRbit(pin)); // clear any outstanding interrupt
  PCICR  |= bit (digitalPinToPCICRbit(pin)); // enable interrupt for the group
}

ISR(PCINT2_vect) {
  buttonPressed = true;
}

#if 1
ISR(TIMER2_COMPA_vect) {
  if (!timerExpired && counter) {
    timerExpired = (--counter == 0);
  }
}
#else
void timer_proc(){
  if (!timerExpired && counter) {
    counter -=2;        
    timerExpired = (counter <= 0);
  }
}
#endif

void select_freq(uint8_t channel) {
  uint16_t freq = pgm_read_word(channelFreqTable + channel);
  rx5808.setFreq(freq);
#ifdef USE_DIVERSITY
  rx5808B.setFreq(freq);
#endif
  chan_scan = -1;
}

void processButton() {
  SELECT_OSD;
  menu_pos = readSwitch();
  saved = false;
  switch (mode) {
    case MAINMENU:
      // a key was pressed so we do nothing
      break;

    case SCANNER:
      // we hit a key in scanner mode so go back to mainmenu
      mode = MAINMENU;
      break;

    case LASTUSED:
      cancelOrSelect(prev_last_used_chans[menu_pos]);
      break;

    case BANDMENU:
      cancelOrSelect(menu_band * 8 + menu_pos);
      break;

    case AUTOSCAN:
      cancelOrSelect(rx5808.getfrom_top8(menu_pos));
      break;
  }
  counter = 500;
}

void cancelOrSelect(uint8_t channel) {
  // if we get a keypress in under 1 second then exit to mainmenu
  if (counter > 400) {
    mode = MAINMENU;
  } else {
    select_freq(channel);
  }
}

void processTimer() {
  // select option and enter
  switch(mode) {
    case MAINMENU:
      switch (menu_pos) {
        case 0: //LAST USED
          if (last_used_chans[0] < 40) {
            mode = LASTUSED;
            select_freq(last_used_chans[0]);
            memcpy(prev_last_used_chans, last_used_chans, 8);
          }
          counter = 500;
          break;

        case 6: //SCANNER
          mode = SCANNER;
          counter = 500;
          break;

        case 7: //AUTOSCAN
          rx5808.compute_top8();
          mode = AUTOSCAN;
          select_freq(rx5808.getfrom_top8(7));
          counter = 500;
          break;

        default:
          menu_band = menu_pos-1;
          mode = BANDMENU;
          select_freq(menu_band * 8 + menu_pos);
          counter = 500;
          break;
      }
      break;

    case SCANNER:
      counter = 500;
      break;

    case LASTUSED:
      if (prev_last_used_chans[menu_pos]>=CHANNEL_MIN && prev_last_used_chans[menu_pos]<CHANNEL_MAX) {
        if (!saved) {
          updateLastUsed(prev_last_used_chans[menu_pos]);
          SELECT_A;
          saved = true;
        }
      }
      break;

    case BANDMENU:
      if (!saved) {
        updateLastUsed(menu_band * 8 + menu_pos);
        SELECT_A;
        saved = true;
      }
      break;

    case AUTOSCAN:
      if (!saved) {
        updateLastUsed(rx5808.getfrom_top8(menu_pos));
        SELECT_A;
        saved = true;
      }
      break;
  }
}

void updateLastUsed(uint8_t channel) {
  int pos = 7;
  for(int i=0 ; i<8 ; i++) {
    if (last_used_chans[i] == channel) {
      pos = i;
      break;
    }
  }
  memmove(last_used_chans+1, last_used_chans, pos);
  last_used_chans[0] = channel;
  eeprom_write_len(last_used_chans, EEPROM_ADDR_LAST_CHAN_ID, sizeof(last_used_chans));
  
}

void redisplay() {
  switch(mode) {
    case MAINMENU:
      display_mainmenu(menu_pos);
      break;

    case LASTUSED:
      display_favorites(menu_pos);
      break;

    case SCANNER:
      display_scanner();
      break;

    case BANDMENU:
      display_bandmenu(menu_pos, menu_band);
      break;

    case AUTOSCAN:
      display_autoscan(menu_pos);
      break;
  }
}

void loop(void) {
  if (mode == MAINMENU || mode == SCANNER) {
    if (chan_scan != -1) {
      rx5808.updateRssi(1, BIN_H, chan_scan);
      if (mode == SCANNER) {
        display_scanner_update(chan_scan);
      }
      chan_scan = (chan_scan + 1) % CHANNEL_MAX;
    } else {
      chan_scan = 0;
    }
    rx5808.setFreq(pgm_read_word_near(channelFreqTable + chan_scan));
  } else {

#ifdef USE_DIVERSITY
    // select best reciever
    uint16_t rssi_a = rx5808.getCurrentRSSI();
    uint16_t rssi_b = rx5808B.getCurrentRSSI();
    if (current_rx == RX_B && rssi_a > rssi_b + RX_HYST) {
      SELECT_A;
      current_rx = RX_A;
    }
    if (current_rx == RX_A && rssi_b > rssi_a + RX_HYST) {
      SELECT_B;
      current_rx = RX_B;
    }
#endif
  }

#ifdef USE_OLED
  delay(30);
#else
  TV.delay(40);
#endif

  if (buttonPressed) {
    processButton();
    buttonPressed = false;
    redisplay();
  } else if (timerExpired) {
    processTimer();
    timerExpired = false;
    redisplay();
  } else {
    if (mode != SCANNER) {
#ifdef USE_OLED
      redisplay();
#else
      display_timer();
#endif
    }
  }
}

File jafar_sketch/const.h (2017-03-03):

/*
This file is part of Fatshark© goggle rx module project (JAFaR).

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
    Copyright © 2016 Michele Martinelli
  */

#ifndef const_h
#define const_h

#include "compat.h"

//#define FORCE_FIRST_MENU_ITEM //force always the first menu item (last freq used)
//#define STANDALONE

//ONLY ONE OF THE FOLLOWING:
#define USE_DIVERSITY
//#define USE_OLED

//#define USE_I2C_OLED

//DEBUG STUFF
//#define DEBUG
//#define ENABLE_RSSILOG
#define FLIP_SCREEN

#define CH1 2
#define CH2 3
#define CH3 4

//calibration stored values
#define EEPROM_ADR_RSSI_MIN_L 2
#define EEPROM_ADR_RSSI_MIN_H 3
#define EEPROM_ADR_RSSI_MAX_L 4
#define EEPROM_ADR_RSSI_MAX_H 5

#define EEPROM_ADDR_LAST_CHAN_ID 8

#define EEPROM_ADDR_START_LOG 20

#define BIN_H 70

//OSD diplay dependant
#define D_COL 120
#define D_ROW 96
#define MENU_Y_SIZE 12

//SPI related
#define spiDataPin 11
#define spiClockPin 13

#define SPI_CSA 10//receiver SPI Select pin
#define rssiA A2  //RSSI input

#define SPI_CSB 8//receiver SPI Select pin
#define rssiB A1  //RSSI input

#define SW_CTRL1 5
#define SW_CTRL2 6

#define SELECT_OSD {digitalWrite(SW_CTRL1, HIGH);digitalWrite(SW_CTRL2, HIGH);}
#define SELECT_A {digitalWrite(SW_CTRL1, LOW);  digitalWrite(SW_CTRL2, HIGH);}
#define SELECT_B {digitalWrite(SW_CTRL1, HIGH);  digitalWrite(SW_CTRL2, LOW);}

#define RX_HYST 15 //~10%

#define RX_A 1
#define RX_B 0

// Channels with their Mhz Values
const uint16_t channelFreqTable[] PROGMEM = {
  // Channel 1 - 8
  5865, 5845, 5825, 5805, 5785, 5765, 5745, 5725, // Band A
  5733, 5752, 5771, 5790, 5809, 5828, 5847, 5866, // Band B
  5705, 5685, 5665, 5645, 5885, 5905, 5925, 5945, // Band E
  5740, 5760, 5780, 5800, 5820, 5840, 5860, 5880, // Band F / Airwave
  5658, 5695, 5732, 5769, 5806, 5843, 5880, 5917  // Raceband
};

// All Channels of the above List ordered by Mhz
const uint8_t channelList[] PROGMEM = {
  19, 32, 18, 17, 33, 16, 7, 34, 8, 24, 6, 9, 25, 5, 35, 10, 26, 4, 11, 27, 3, 36, 12, 28, 2, 13, 29, 37, 1, 14, 30, 0, 15, 31, 38, 20, 21, 39, 22, 23
};

const uint8_t channelNames[] PROGMEM = {
  0xA1, 0xA2, 0xA3, 0xA4, 0xA5, 0xA6, 0xA7, 0xA8,
  0xB1, 0xB2, 0xB3, 0xB4, 0xB5, 0xB6, 0xB7, 0xB8,
  0xE1, 0xE2, 0xE3, 0xE4, 0xE5, 0xE6, 0xE7, 0xE8,
  0xF1, 0xF2, 0xF3, 0xF4, 0xF5, 0xF6, 0xF7, 0xF8,
  0xC1, 0xC2, 0xC3, 0xC4, 0xC5, 0xC6, 0xC7, 0xC8
};


void NOINLINE eeprom_read_len(byte *p, uint16_t e, uint16_t l);
NOINLINE void eeprom_write_len(byte *p, uint16_t e, uint16_t l);

uint16_t  eeprom_read_word(uint16_t addr);
void eeprom_write_word(uint16_t addr, uint16_t w);

void pciSetup(byte pin);
uint8_t readSwitch();
void cancelOrSelect(uint8_t channel);
void updateLastUsed(uint8_t channel);

#endif

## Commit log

2016-04-15 diversity ready version - TESTED
    [rx_mod.brd, rx_mod.sch]
2016-04-15 first version - antenna position reworked
    [div_mod.brd, div_mod.sch]
2016-04-19 regulator, buffer and new SMA connetor. v1.1
    [div_mod.brd, div_mod.sch]
2016-04-19 new SMA connetor
    [rx_mod.brd, rx_mod.sch]
2016-04-19 add BOM
2016-04-20 LDO name replaced
    [div_mod.brd, div_mod.sch]
2016-04-22 removing wrong version of diversity module
    [div_mod.brd, div_mod.sch]
2016-04-22 removing wrong version of pcbs
2016-04-22 diversity module v1.1
    [div_mod.brd, div_mod.sch]
2016-05-20 base module V3.2
    [rx_mod.brd, rx_mod.sch]
2016-05-20 moved to subdir
    [rx_mod.brd, rx_mod.sch]
2016-05-20 moved diversity board to testing branch
    [div_mod.brd, div_mod.sch]
2016-05-20 diversity module v2.0
    [div_mod.brd, div_mod.sch]
2016-05-20 base module v4.0
    [rx_mod.brd, rx_mod.sch]
2016-05-20 diversity board V2.0
    [div_mod.brd]
2016-05-27 new version pcb images
2016-05-27 diversity board v2.1
    [div_mod.brd, div_mod.sch]
2016-05-27 BOM update
2016-06-26 first OLED version, OSD must be fixed
    [const.h, jafar_sketch.ino]
2016-06-26 force timer=0 at the end of submenu selection
2016-07-05 add oled pcb and U8g lib, fix docs
    [div_mod.brd, div_mod.sch, oled_mod.brd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]
2016-07-05 spi-mod docs
2016-07-05 spi-mod image dimension
2016-07-09 add looptime and fixes...
    [const.h, jafar_oled.ino, jafar_osd.ino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]
2016-07-09 fix minor bugs and add connections picture
    [const.h, jafar_osd.ino, jafar_sketch.ino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]
2016-07-09 fix a bug with RSSI reading
    [jafar_osd.ino, jafar_sketch.ino, rx5808.ino]
2016-07-09 fix RSSI read avg bug
    [jafar_osd.ino, jafar_sketch.ino, rx5808.ino]
2016-07-17 solved a bug in the submenu selection
    [const.h, jafar_osd.ino, jafar_sketch.ino]
2016-07-30 switch gnd and vcc on silkscreen
    [div_mod.brd, div_mod.sch, oled_mod.brd]
2016-08-02 flip OLED screen define
    [const.h, jafar_oled.ino]
2016-08-03 initial timer value changed to 5 seconds
2016-09-18 add I2C oled support
2016-09-24 Better handling of empty slots in the favourites list.
2016-09-24 Use hardware SPI for talking to the receiver.
2017-03-03 latest from grandparents
    [div_mod.brd, div_mod.sch, rx_mod.brd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]

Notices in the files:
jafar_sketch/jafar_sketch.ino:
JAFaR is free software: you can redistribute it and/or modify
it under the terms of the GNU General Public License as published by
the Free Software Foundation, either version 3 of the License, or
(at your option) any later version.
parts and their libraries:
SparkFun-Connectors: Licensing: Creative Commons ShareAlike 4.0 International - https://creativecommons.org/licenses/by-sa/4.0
